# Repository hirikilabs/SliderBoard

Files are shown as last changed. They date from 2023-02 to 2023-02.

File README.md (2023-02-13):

# SliderBoard

PCB para control de sliders y microsliders(macro) para fotografía.

## Documentación:

* Slider: https://lab.medialab.tabakalera.eus/proyecto/slider/
* Macro: https://lab.medialab.tabakalera.eus/proyecto/macrofotografia-extrema-automatizado/

## Firmwares:

* Control Slider: https://github.com/hirikilabs/AlbertoSlider
* Control Macro: https://github.com/hirikilabs/AlbertoMacro

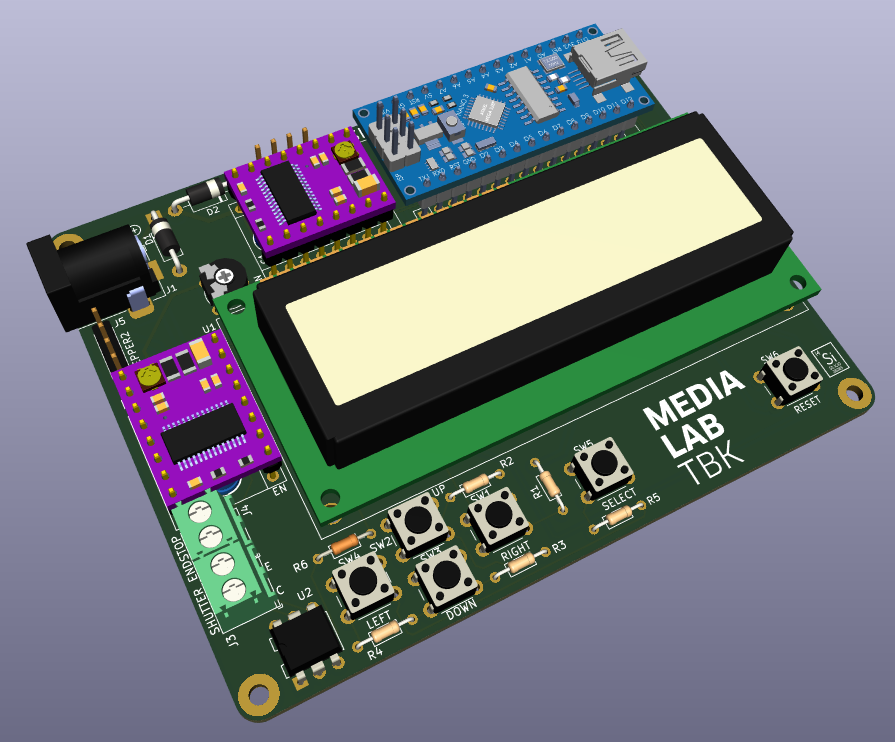
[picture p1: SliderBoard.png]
Sliderboard


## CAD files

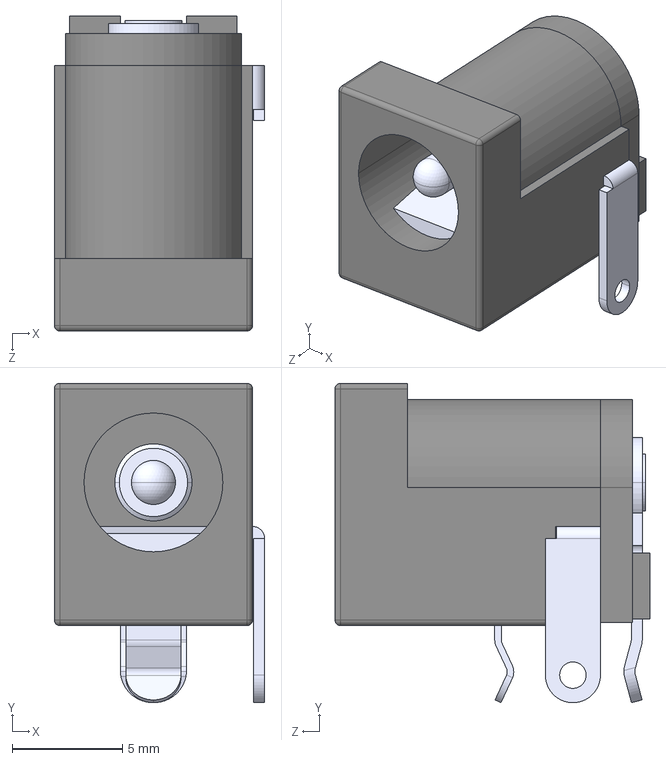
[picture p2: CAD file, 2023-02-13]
3D/DCJ200-10-A-K1-K--3DModel-STEP-56544.STEP
9.55 x 14.5 x 14.3 mm

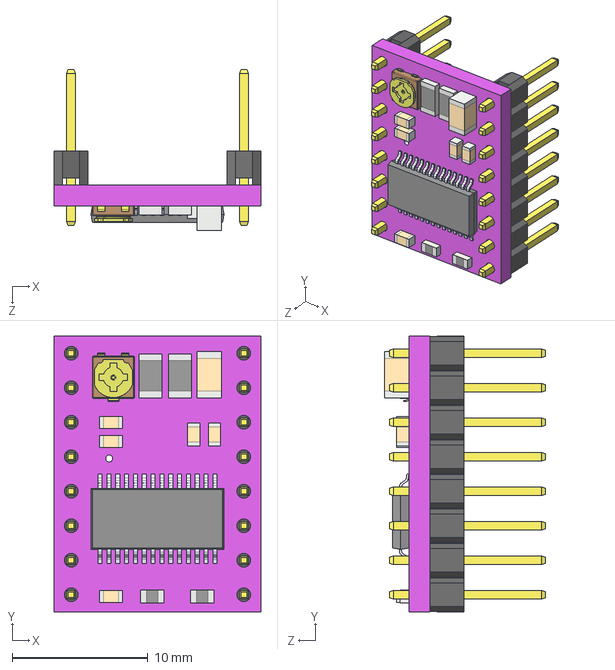
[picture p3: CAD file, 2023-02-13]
3D/drv8825-stepper-motor-driver-carrier-high-current.step
15.2 x 20.3 x 11.9 mm

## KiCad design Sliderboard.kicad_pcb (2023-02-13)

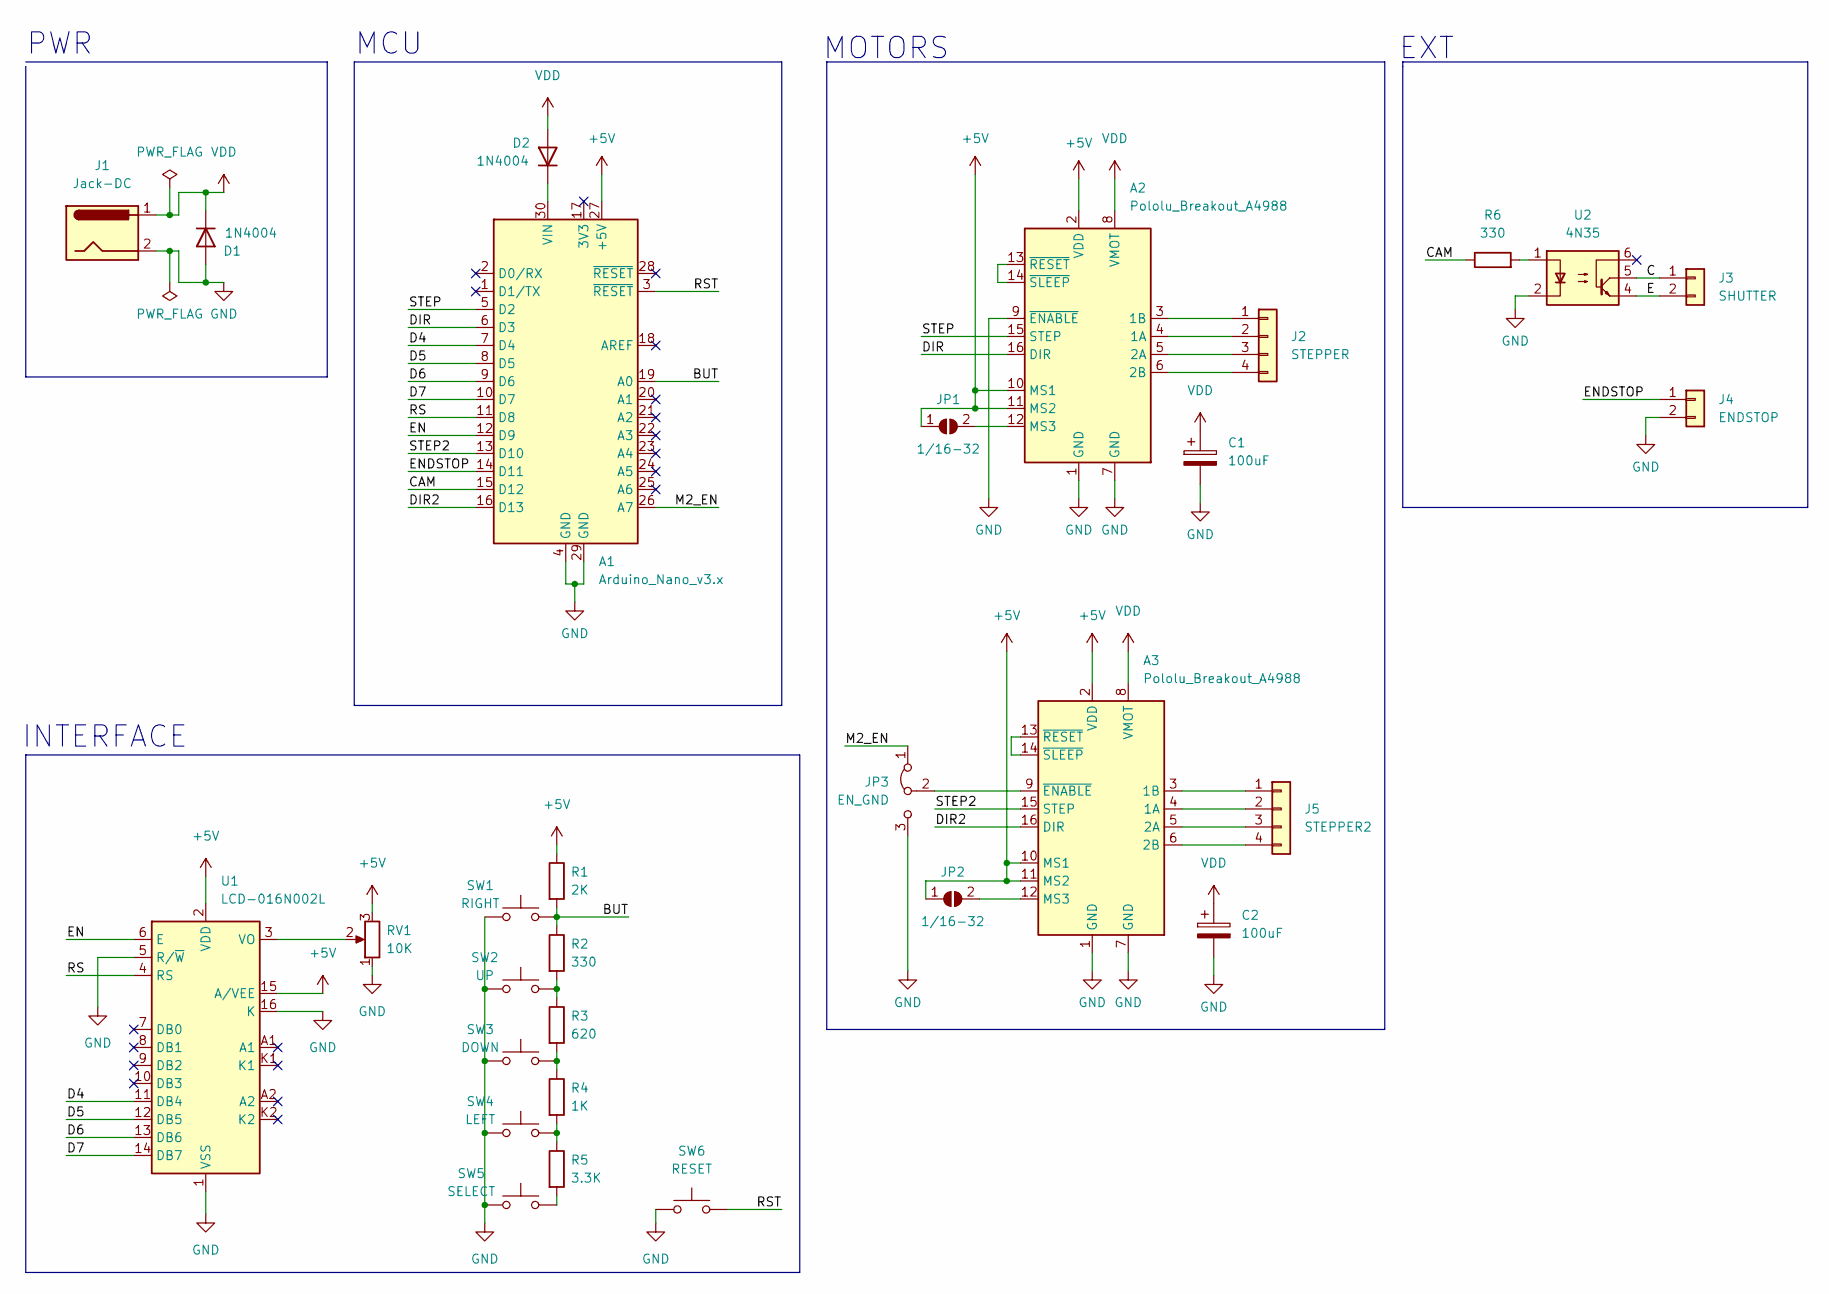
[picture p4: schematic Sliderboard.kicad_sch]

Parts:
A1: Arduino_Nano_v3.x; Arduino_Nano
A2, A3: Pololu_Breakout_A4988; Pololu_Breakout-16_15.2x20.3mm
C1, C2: 100uF; CP_Radial_D5.0mm_P2.00mm
D1, D2: 1N4004; D_DO-41_SOD81_P10.16mm_Horizontal
J1: Jack-DC; BarrelJack_Horizontal
J2: STEPPER; PinHeader_1x04_P2.54mm_Vertical
J3: SHUTTER; TerminalBlock_Phoenix_PT-1,5-2-3.5-H_1x02_P3.50mm_Horizontal
J4: ENDSTOP; TerminalBlock_Phoenix_PT-1,5-2-3.5-H_1x02_P3.50mm_Horizontal
J5: STEPPER2; PinHeader_1x04_P2.54mm_Vertical
JP1, JP2: 1/16-32; SolderJumper-2_P1.3mm_Open_RoundedPad1.0x1.5mm
JP3: EN_GND; SolderJumper-3_P1.3mm_Bridged2Bar12_RoundedPad1.0x1.5mm
R1: 2K; R_Axial_DIN0204_L3.6mm_D1.6mm_P7.62mm_Horizontal
R2, R6: 330; R_Axial_DIN0204_L3.6mm_D1.6mm_P7.62mm_Horizontal
R3: 620; R_Axial_DIN0204_L3.6mm_D1.6mm_P7.62mm_Horizontal
R4: 1K; R_Axial_DIN0204_L3.6mm_D1.6mm_P7.62mm_Horizontal
R5: 3.3K; R_Axial_DIN0204_L3.6mm_D1.6mm_P7.62mm_Horizontal
RV1: 10K; Potentiometer_Piher_PT-6-V_Vertical
SW1: RIGHT; SW_PUSH_6mm
SW2: UP; SW_PUSH_6mm
SW3: DOWN; SW_PUSH_6mm
SW4: LEFT; SW_PUSH_6mm
SW5: SELECT; SW_PUSH_6mm
SW6: RESET; SW_PUSH_6mm
U1: LCD-016N002L; WC1602A
U2: 4N35; DIP-6_W7.62mm

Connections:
+5V: A1.27 (+5V), A2.2 (VDD), A2.10 (MS1), A2.11 (MS2), A3.2 (VDD), A3.10 (MS1), A3.11 (MS2), JP1.1 (A), JP2.1 (A), R1.1, RV1.3, U1.2 (VDD), U1.15 (A/VEE)
/BUT: A1.19 (A0), R1.2, R2.1, SW1.2
/C: J3.1, U2.5
/CAM: A1.15 (D12), R6.1
/D4: A1.7 (D4), U1.11 (DB4)
/D5: A1.8 (D5), U1.12 (DB5)
/D6: A1.9 (D6), U1.13 (DB6)
/D7: A1.10 (D7), U1.14 (DB7)
/DIR: A1.6 (D3), A2.16 (DIR)
/DIR2: A1.16 (D13), A3.16 (DIR)
/E: J3.2, U2.4
/EN: A1.12 (D9), U1.6 (E)
/ENDSTOP: A1.14 (D11), J4.1
/M2_EN: A1.26 (A7), JP3.1 (A)
/RS: A1.11 (D8), U1.4 (RS)
/RST: A1.3 (~RESET), SW6.2
/STEP: A1.5 (D2), A2.15 (STEP)
/STEP2: A1.13 (D10), A3.15 (STEP)
GND: A1.4 (GND), A1.29 (GND), A2.1 (GND), A2.7 (GND), A2.9 (~ENABLE), A3.1 (GND), A3.7 (GND), C1.2, C2.2, D1.2 (A), J1.2, J4.2, JP3.3 (B), RV1.1, SW1.1, SW2.1, SW3.1, SW4.1, SW5.1, SW6.1, U1.1 (VSS), U1.5 (R/~W), U1.16 (K), U2.2
unnamed: A1.30 (VIN), D2.1 (K)
unnamed: A2.3 (1B), J2.1
unnamed: A2.4 (1A), J2.2
unnamed: A2.5 (2A), J2.3
unnamed: A2.6 (2B), J2.4
unnamed: A2.12 (MS3), JP1.2 (B)
unnamed: A2.13 (~RESET), A2.14 (~SLEEP)
unnamed: A3.3 (1B), J5.1
unnamed: A3.4 (1A), J5.2
unnamed: A3.5 (2A), J5.3
unnamed: A3.6 (2B), J5.4
unnamed: A3.9 (~ENABLE), JP3.2 (C)
unnamed: A3.12 (MS3), JP2.2 (B)
unnamed: A3.13 (~RESET), A3.14 (~SLEEP)
unnamed: R2.2, R3.1, SW2.2
unnamed: R3.2, R4.1, SW3.2
unnamed: R4.2, R5.1, SW4.2
unnamed: R5.2, SW5.2
unnamed: R6.2, U2.1
unnamed: RV1.2, U1.3 (VO)
VDD: A2.8 (VMOT), A3.8 (VMOT), C1.1, C2.1, D1.1 (K), D2.2 (A), J1.1

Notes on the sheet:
MCU
INTERFACE
EXT
MOTORS
PWR

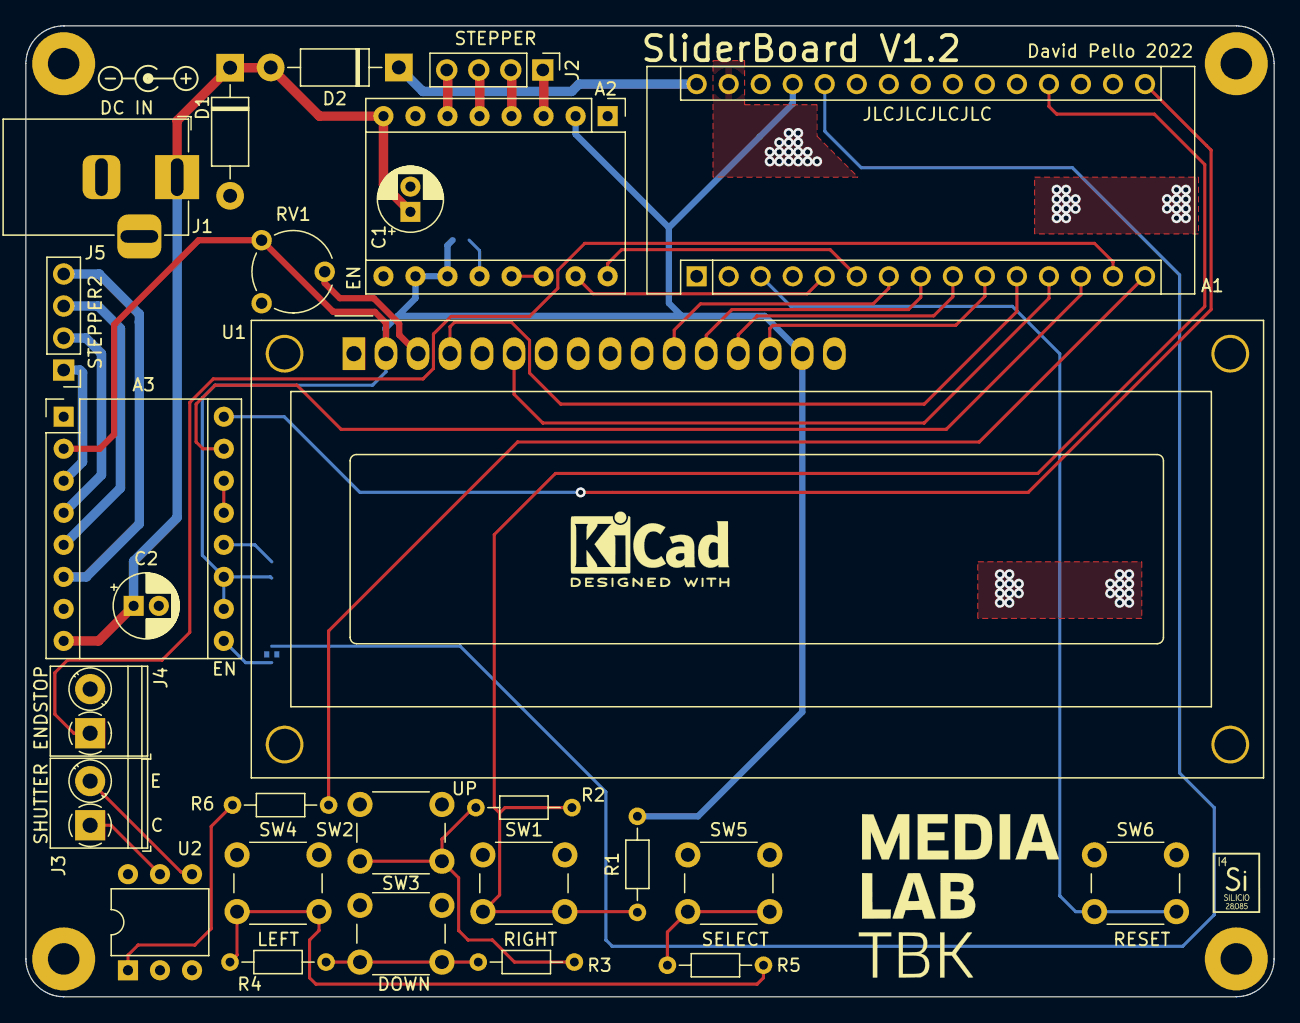
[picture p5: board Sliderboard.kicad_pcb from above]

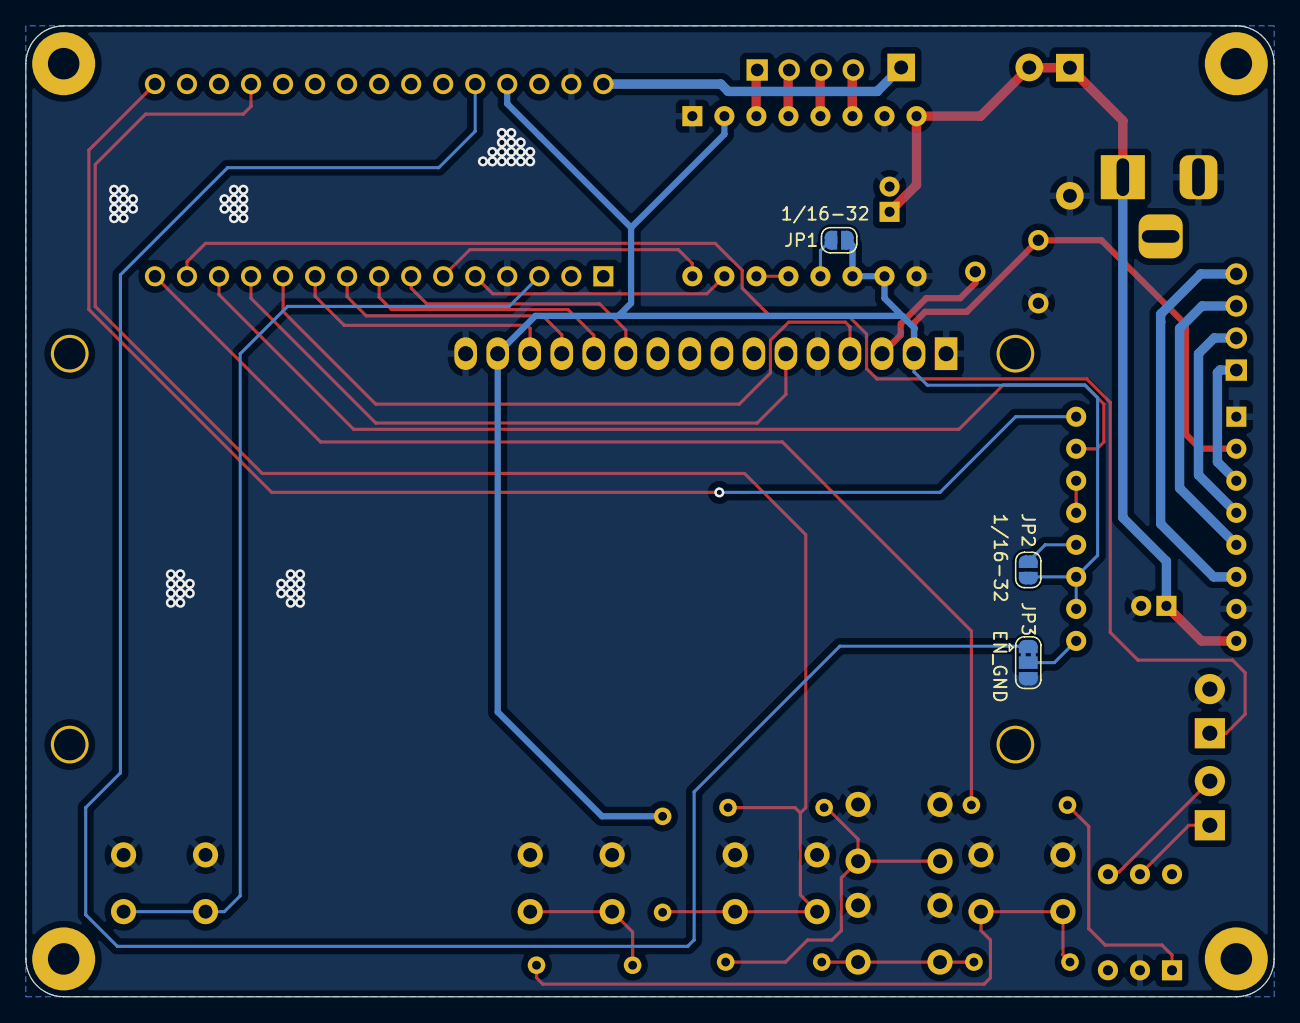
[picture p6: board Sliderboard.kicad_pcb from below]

Board: 2 copper layers, 99.0 x 77.0 mm, 30 parts (3 on the bottom side), 40 nets.
